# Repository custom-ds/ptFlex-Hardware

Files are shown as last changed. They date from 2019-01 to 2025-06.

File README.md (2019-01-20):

# Project: Traveler ptFlex
Following the sunsetting of the PTMini project, the ptFlex is the second generation of the ArduinoTrack APRS tracker.  

The ptFlex is based on the same ATMega processor and much of the same hardware as the ArduinoTrack, but a newer and smaller form factor.  The new form factor removes the larger Arduino Shield connectors that proved to be fragile and rarely used.  Instead, the digial pins have been replaced with a single "Qwiic" connector, conforming to Sparkfun's Qwiic standards.

[Sparkfun Qwiic Connector Standard](https://www.sparkfun.com/qwiic)

Board version 1.0.3 is release-candidate level, and is currently undergoing flight testing.

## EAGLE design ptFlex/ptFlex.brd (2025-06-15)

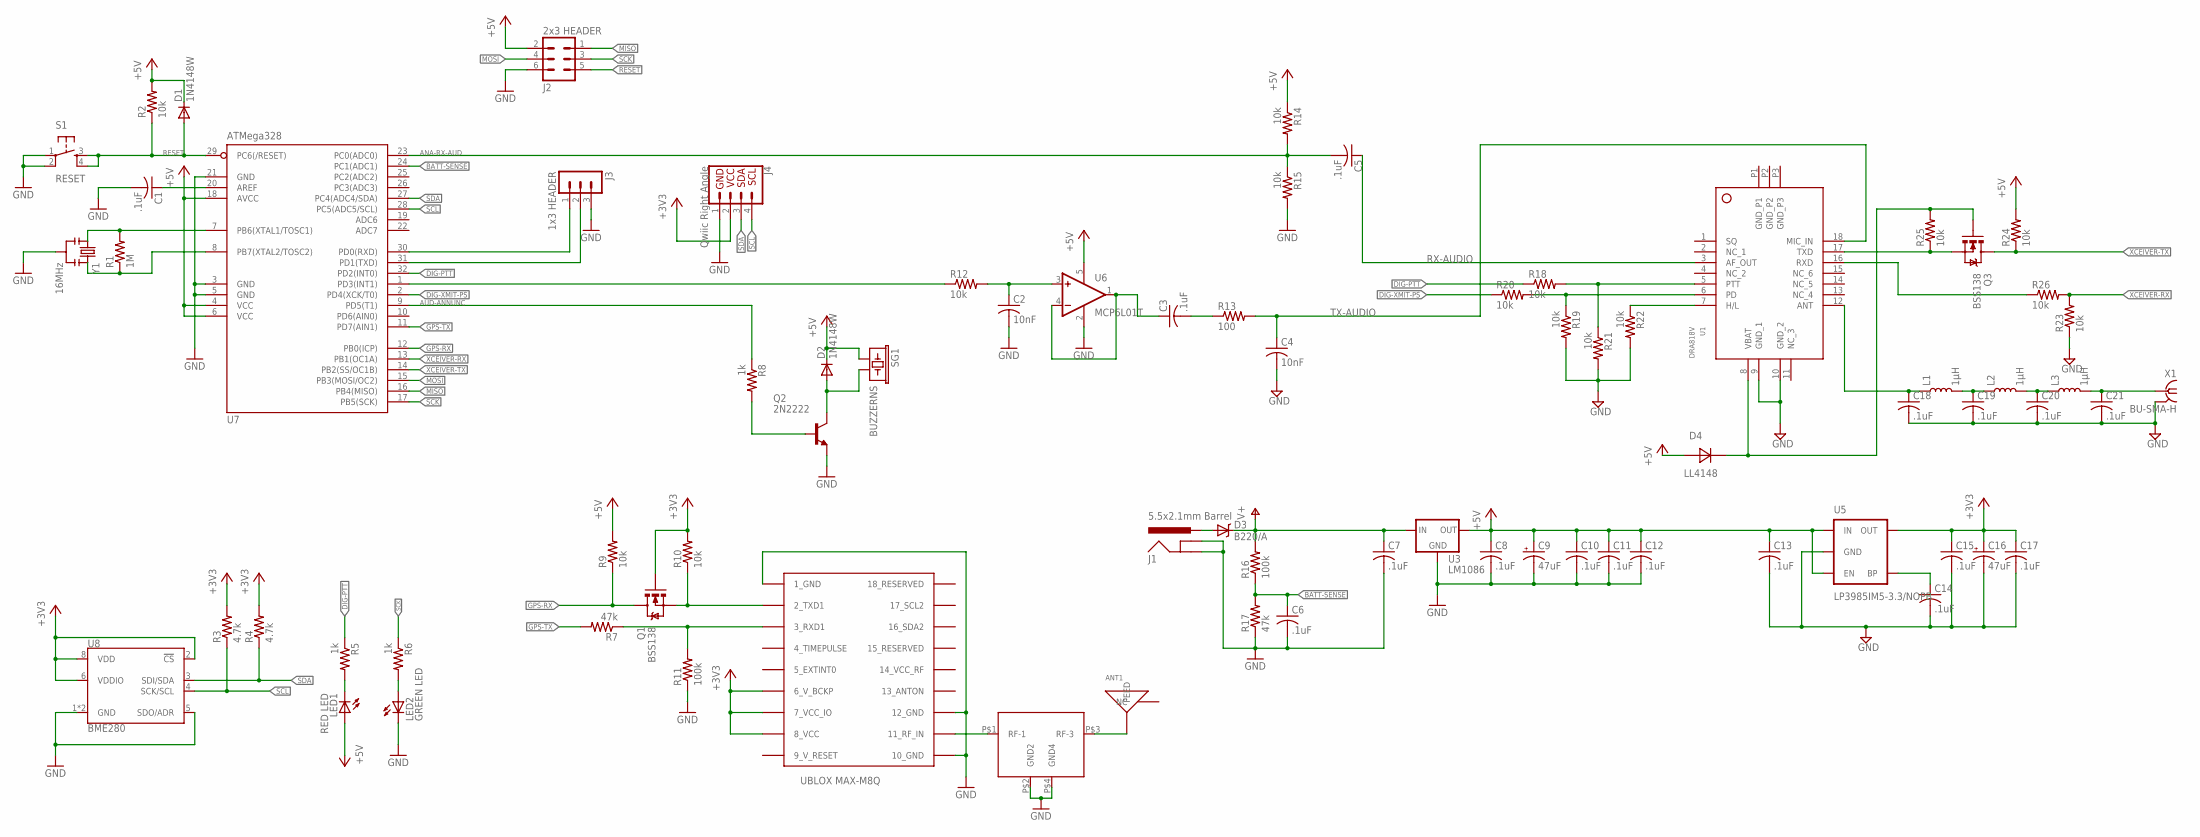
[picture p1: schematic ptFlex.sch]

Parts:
ANT1: GPS ANTENNA; 1575AT43A40; DIGIKEY 712-1003-1-ND
C1, C3, C5, C6, C7, C8, C10, C11, C12, C13, C14, C15, C17, C18, C19, C20, C21: .1uF; C0805; DIGIKEY 311-1361-1-ND
C2, C4: 10nF; C0805; DIGIKEY 399-1158-1-ND
C9, C16: 47uF; 153CLV-0605; DIGIKEY PCE3842CT-ND
D1, D2: 1N4148W; SOD123; DIGIKEY 1N4148W-FDICT-ND
D3: B220/A; SMA-DIODE; DIGIKEY 641-1258-1-ND
D4: LL4148; SOD-80
F1: MURATA-GPS-FILTER; DIGIKEY 583-1198-1-ND
J1: 5.5x2.1mm Barrel; POWER_JACK_SMD; DIGIKEY CP-002AHPJCT-ND
J2: 2x3 HEADER; MA03-2; DIGIKEY 952-2121-ND
J3: 1x3 HEADER; MA03-1; DIGIKEY 952-2264-ND
J4: Qwiic Right Angle; 1X04_1MM_RA; DIGIKEY 455-1804-1-ND
L1, L2, L3: 1µH; L0805
LED1: RED LED; CHIPLED_1206; DIGIKEY 160-1405-1-ND
LED2: GREEN LED; CHIPLED_1206; DIGIKEY 160-1169-1-ND
Q1, Q3: BSS138; SOT23; DIGIKEY BSS138KCT-ND
Q2: 2N2222; SOT23-BEC; DIGIKEY MMBT2222AFSCT-ND
R1: 1M; R0805; DIGIKEY 311-1.0MARCT-ND
R2, R9, R10, R12, R14, R15, R18, R19, R20, R21, R22, R23, R24, R25, R26: 10k; R0805; DIGIKEY 311-10.0KCRCT-ND
R3, R4: 4.7k; R0805; DIGIKEY 311-4.7KARCT-ND
R5, R6, R8: 1k; R0805; DIGIKEY 311-1.0KARCT-ND
R7, R17: 47k; R0805; DIGIKEY 311-47.0KCRCT-ND
R11, R16: 100k; R0805; DIGIKEY 311-100KCRCT-ND
R13: 100; R0805; DIGIKEY 311-100ARCT-ND
S1: RESET; TACTILE_SWITCH_SMD; DIGIKEY CKN9104CT-ND
SG1: BUZZERNS; BUZZER-12MM-NS; DIGIKEY 102-1155-ND
U1: DRA818V; SMD_DRA818
U2: UBLOX_MAX; DIGIKEY 672-1003-1-ND
U3: LM1086; TO263; DIGIKEY LM1086ISX-5.0/NOPBCT-ND
U5: LP3985IM5-3.3/NOPB; SOT23-5; DIGIKEY LP3985IM5-3.3/NOPBCT-ND
U6: MCP6L01T; SOT23-5; DIGIKEY MCP6L01T-E/OTCT-ND
U7: ATMega328; TQFP32-08; DIGIKEY ATMEGA328P-AU-ND
U8: BME280; LGA-8-2.5X2.5; DIGIKEY 828-1063-1-ND
X1: BU-SMA-H; DIGIKEY CONSMA001-ND
Y1: 16MHz; RESONATOR-SMD; DIGIKEY 478-5420-1-ND

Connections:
9_V_RESET: U2.9_V_RESET
+3V3: C15.1, C16.+, C17.1, J4.2, Q1.1 (G), R3.2, R4.2, R10.2, U2.6_V_BCKP, U2.7_VCC_IO, U2.8_VCC, U5.5 (OUT), U8.2 (!CS), U8.6 (VDDIO), U8.8 (VDD)
+5V: C8.1, C9.+, C10.1, C11.1, C12.1, C13.1, D1.C, D2.C, D4.ANODE, J2.2, LED1.A, R2.2, R9.2, R14.1, R24.2, SG1.+ (1), U3.2 (OUT), U5.1 (IN), U5.3 (EN), U6.5 (V+), U7.4 (VCC), U7.6 (VCC), U7.18 (AVCC)
ANA-RX-AUD: C5.2, R14.2, R15.1, U7.23 (PC0(ADC0))
AUD-ANNUNC: R8.1, U7.9 (PD5(T1))
BATT-SENSE: C6.1, R16.1, R17.2, U7.24 (PC1(ADC1))
DIG-PTT: R5.1, R18.1, U7.32 (PD2(INT0))
DIG-XMIT-PS: R20.1, U7.2 (PD4(XCK/T0))
GND: C1.2, C2.2, C4.2, C6.2, C7.2, C8.2, C9.-, C10.2, C11.2, C12.2, C13.2, C14.2, C15.2, C16.-, C17.2, C18.2, C19.2, C20.2, C21.2, F1.P$2 (GND2), F1.P$4 (GND4), J1.GND (GNDBREAK), J1.P$4 (GND), J2.6, J3.3, J4.1, LED2.C, Q2.E, R11.1, R15.2, R17.1, R19.2, R21.2, R22.2, R23.1, S1.1, S1.2, U1.9 (GND_1), U1.10 (GND_2), U2.1_GND, U2.10_GND, U2.12_GND, U3.1 (GND), U5.2 (GND), U6.2 (V-), U7.3 (GND), U7.5 (GND), U7.21 (GND), U8.1 (GND), U8.5 (SDO/ADR), U8.7 (GND), X1.2, X1.3 (2), X1.4 (2), X1.5 (2), Y1.2
GPS-RX: Q1.3 (D), R9.1, U7.12 (PB0(ICP))
GPS-TX: R7.2, U7.11 (PD7(AIN1))
MISO: J2.1, U7.16 (PB4(MISO))
MOSI: J2.4, U7.15 (PB3(MOSI/OC2))
unnamed: C2.1, R12.2, U6.3 (+IN)
unnamed: F1.P$1 (RF-1), U2.11_RF_IN
unnamed: ANT1.FEED, F1.P$3 (RF-3)
unnamed: C20.1, L2.2, L3.1
unnamed: C19.1, L1.2, L2.1
unnamed: C18.1, L1.1, U1.12 (ANT)
unnamed: C21.1, L3.2, X1.1
unnamed: D3.A, J1.VIN0 (PWR)
unnamed: D2.A, Q2.C, SG1.- (2)
unnamed: C4.1, R13.2, U1.18 (MIC_IN)
unnamed: C3.1, U6.1 (OUT), U6.4 (-IN)
unnamed: D4.CATHODE, Q3.1 (G), R25.2, U1.8 (VBAT)
unnamed: R12.1, U7.1 (PD3(INT1))
unnamed: R18.2, R21.1, U1.5 (PTT)
unnamed: Q1.2 (S), R10.1, U2.2_TXD1
unnamed: R19.1, R20.2, U1.6 (PD)
unnamed: R1.1, U7.8 (PB7(XTAL2/TOSC2)), Y1.3
unnamed: R7.1, R11.2, U2.3_RXD1
unnamed: R22.1, U1.7 (H/L)
unnamed: Q3.2 (S), R25.1, U1.17 (TXD)
unnamed: LED1.C, R5.2
unnamed: LED2.A, R6.2
unnamed: Q2.B, R8.2
unnamed: R26.1, U1.16 (RXD)
unnamed: C1.1, U7.20 (AREF)
unnamed: C14.1, U5.4 (BP)
unnamed: R1.2, U7.7 (PB6(XTAL1/TOSC1)), Y1.1
RESET: D1.A, J2.5, R2.1, S1.3, S1.4, U7.29 (PC6(/RESET))
RX-AUDIO: C5.1, U1.3 (AF_OUT)
RXD: J3.1, U7.30 (PD0(RXD))
SCK: J2.3, R6.1, U7.17 (PB5(SCK))
SCL: J4.4, R3.1, U7.28 (PC5(ADC5/SCL)), U8.4 (SCK/SCL)
SDA: J4.3, R4.1, U7.27 (PC4(ADC4/SDA)), U8.3 (SDI/SDA)
TX-AUDIO: C3.2, R13.1
TXD: J3.2, U7.31 (PD1(TXD))
V+: C7.1, D3.C, R16.2, U3.3 (IN)
XCEIVER-RX: R23.2, R26.2, U7.13 (PB1(OC1A))
XCEIVER-TX: Q3.3 (D), R24.1, U7.14 (PB2(SS/OC1B))

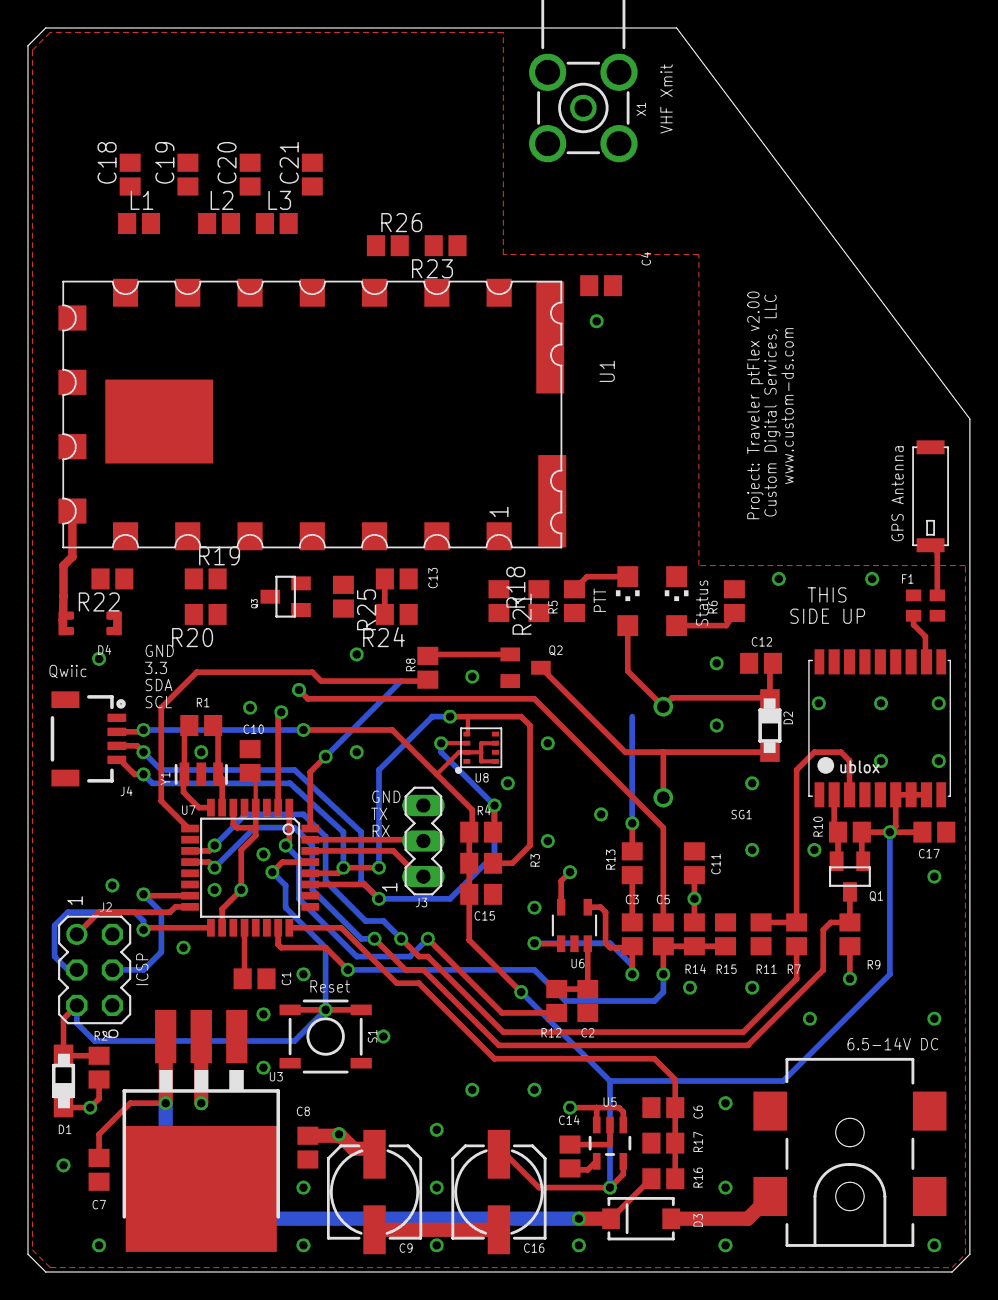
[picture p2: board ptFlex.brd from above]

Board: 4 copper layers, 67.3 x 88.9 mm, 76 parts (0 on the bottom side), 50 nets.

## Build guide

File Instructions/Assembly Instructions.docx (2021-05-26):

# Project: Traveler ptFlex v1.03

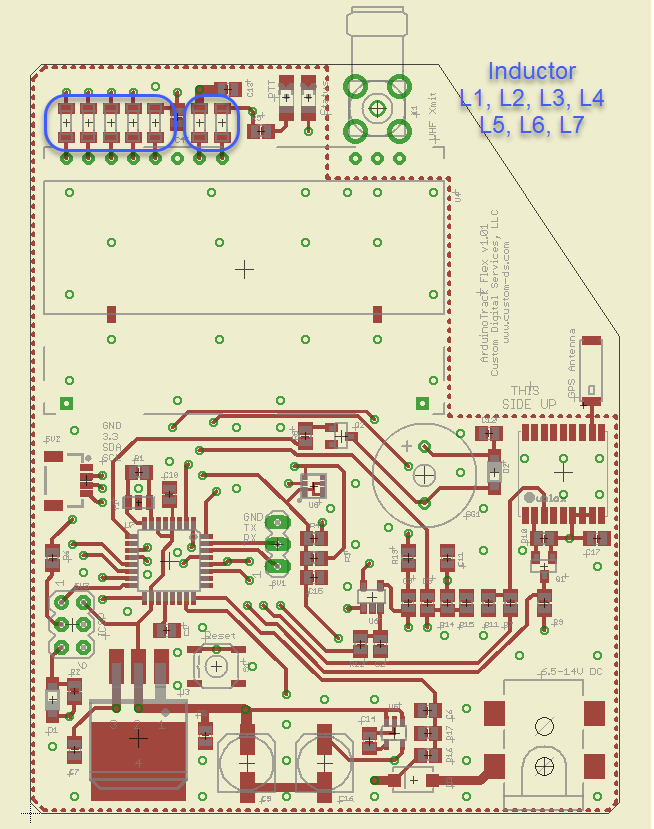
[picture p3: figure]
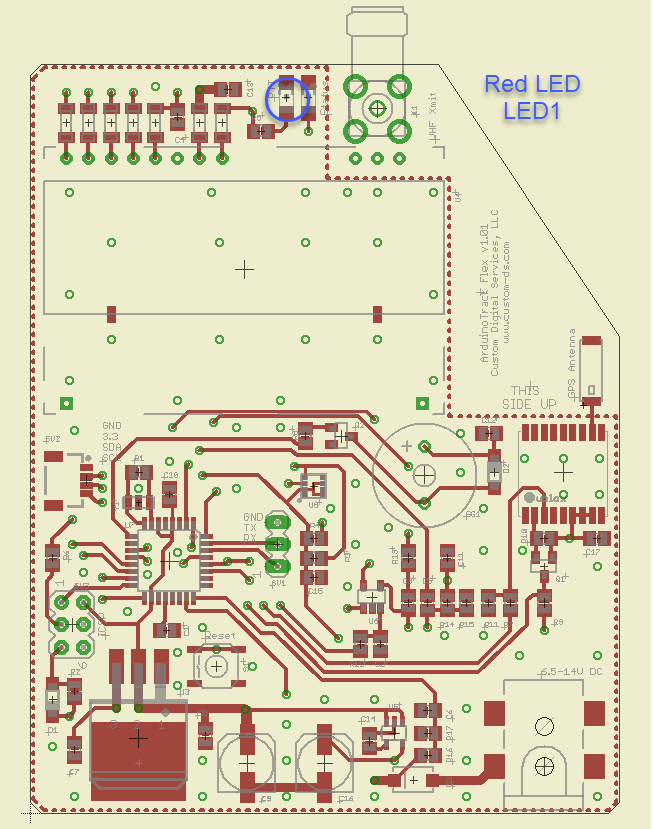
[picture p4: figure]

Inductors L1-L7 - 160Ω Notes: | Red LED LED1 Notes: Dark stripe to the top edge of PCB.

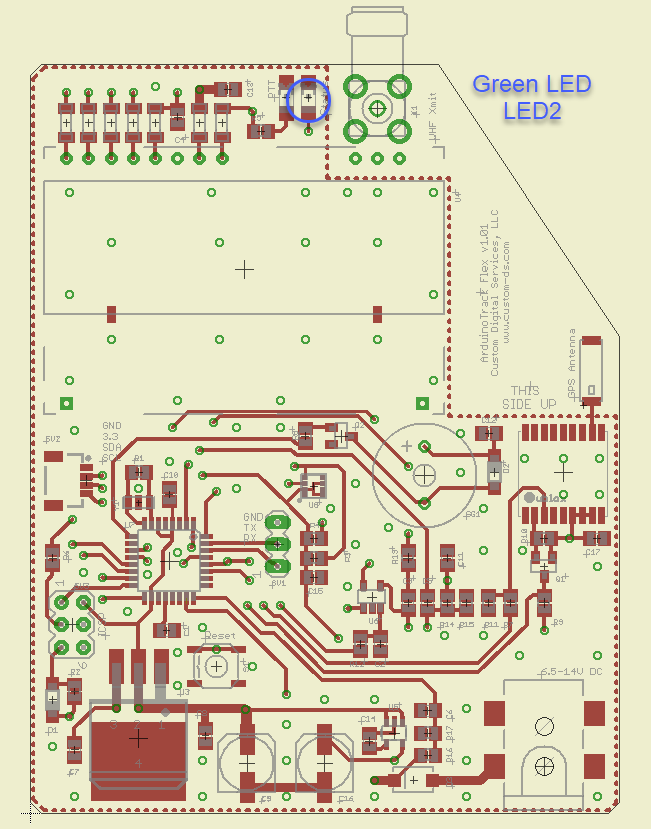
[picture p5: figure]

Green LED LED2 Notes: Dark stripe to the top edge of PCB. | MOSFET Q1 Notes:

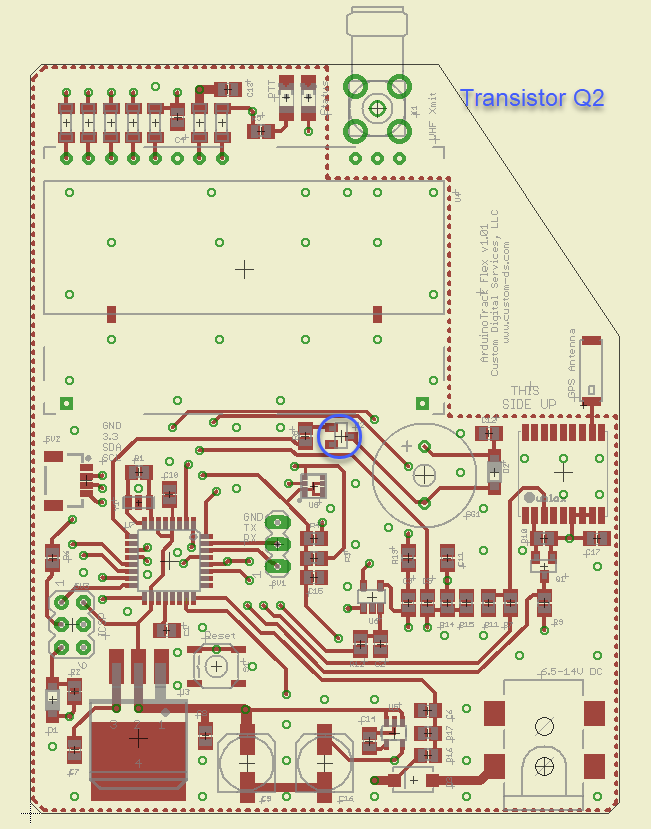
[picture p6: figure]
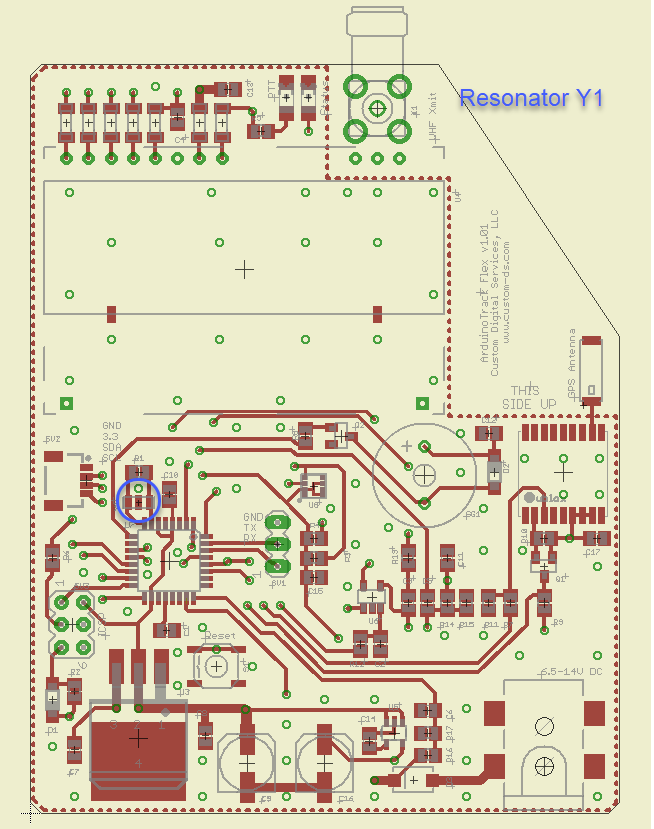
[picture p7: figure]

Transistor Q2 Notes: | Resonator Y1 Notes: 16MHz

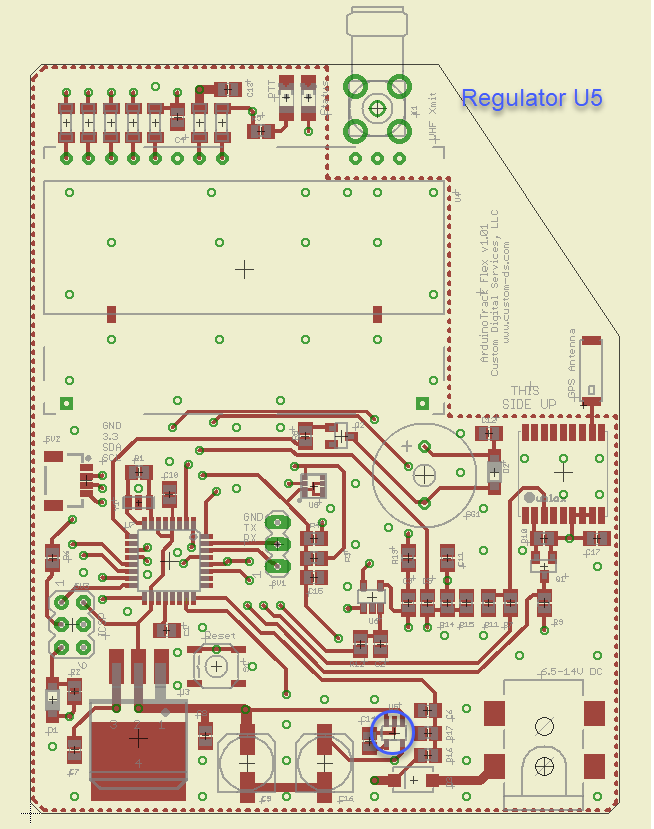
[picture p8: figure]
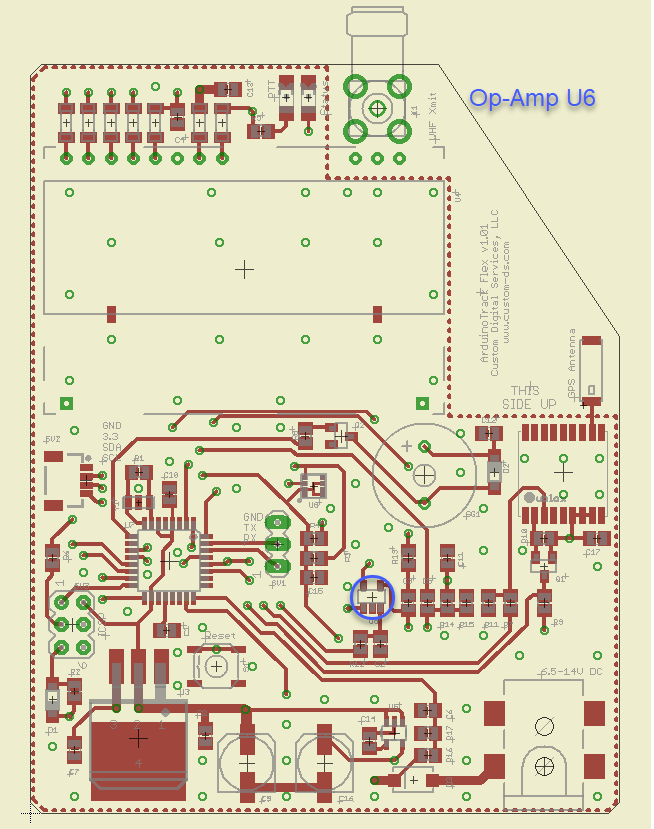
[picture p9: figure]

Regulator U5 Notes: | OpAmp U6 Notes:

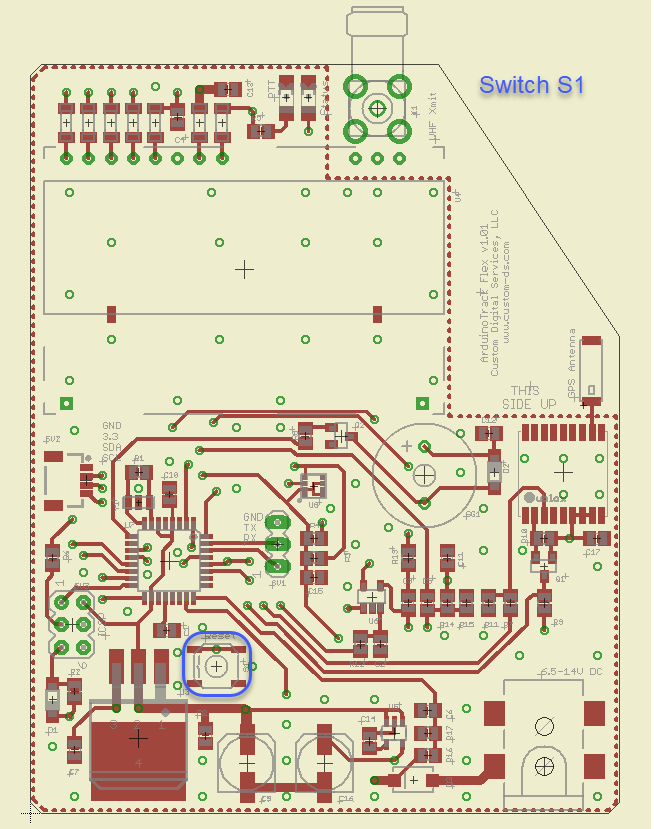
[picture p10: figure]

Switch S1 Notes: | Resistor R1 Notes: 1MΩ (Marking 105 or 1004)

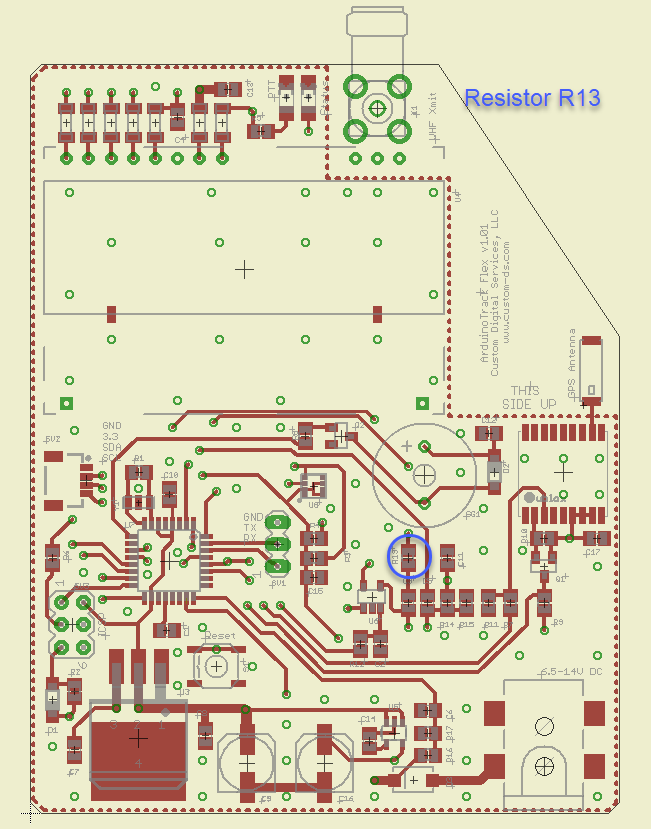
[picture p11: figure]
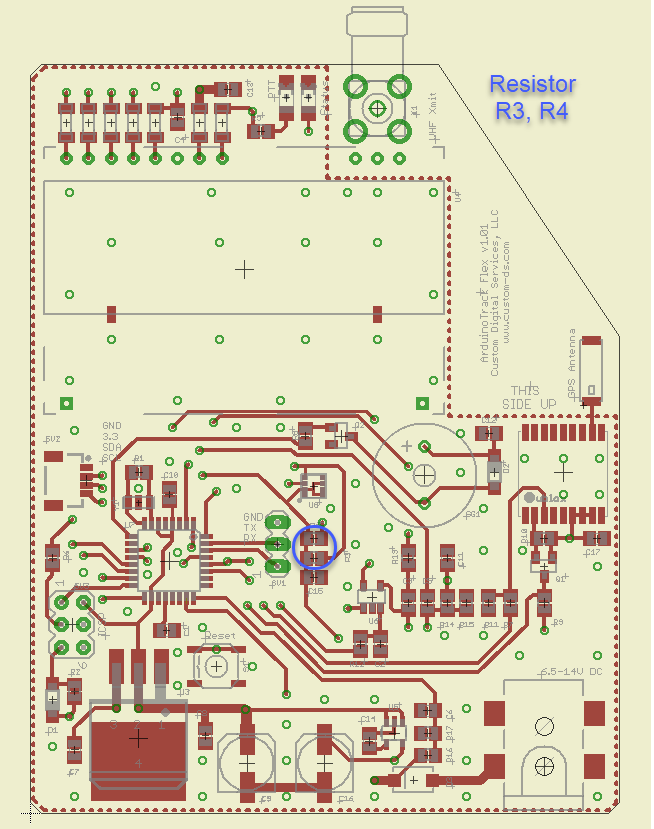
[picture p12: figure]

Resistor R13 Notes: 100Ω (Marking 101 or 1000) | Resistor R3-R4 Notes: 4.7kΩ (Marking 472 or 4701)

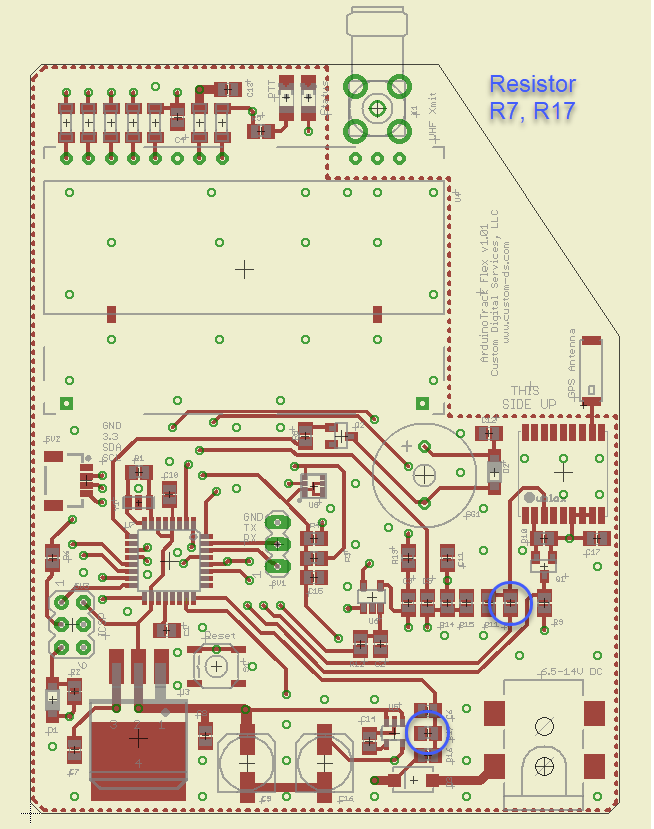
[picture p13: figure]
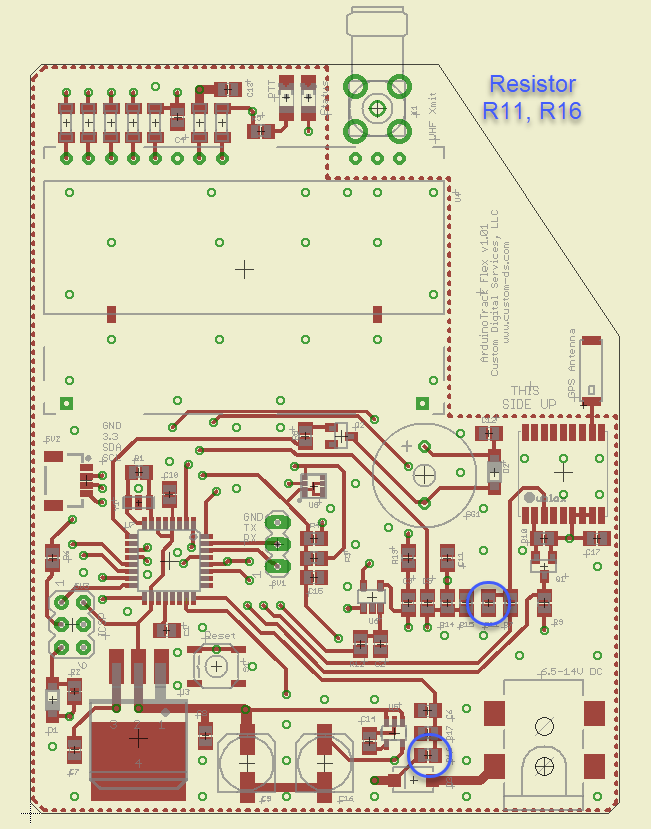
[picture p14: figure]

Resistor R7, R17 Notes: 47kΩ (Marking 473 or 4702) | Resistor R11, R16 Notes: 100kΩ (Marking 104 or 1003)

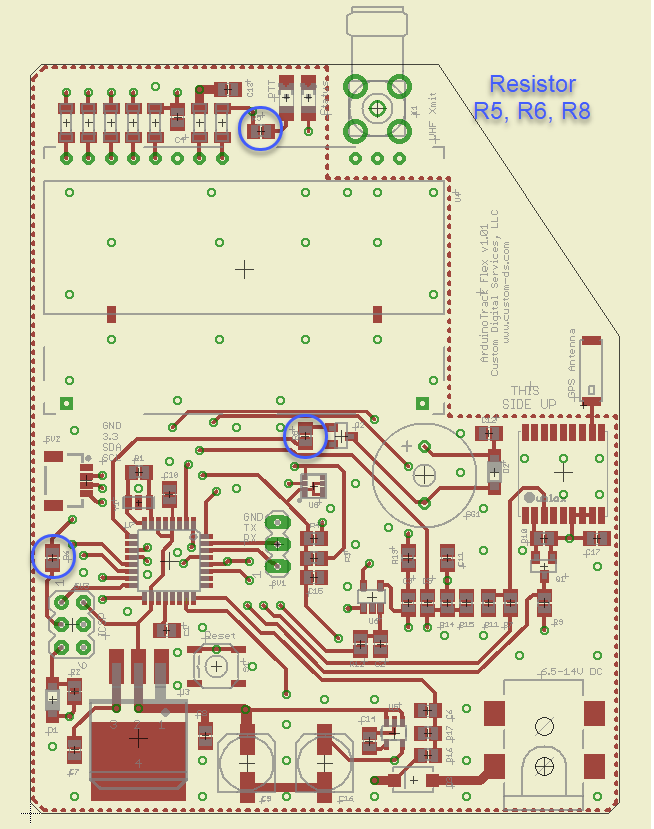
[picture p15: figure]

Resistor R5, R6, R8 Notes: 1kΩ (Marking 102 or 1001) | Resistor R2, R9, R10, R12, R14, R15 Notes: 10kΩ (Marking 103 or 1002)

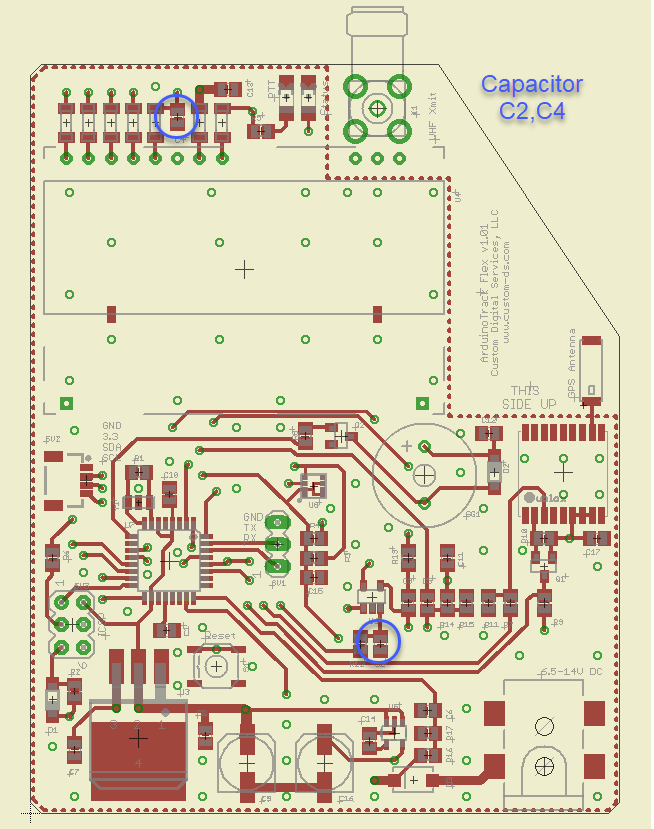
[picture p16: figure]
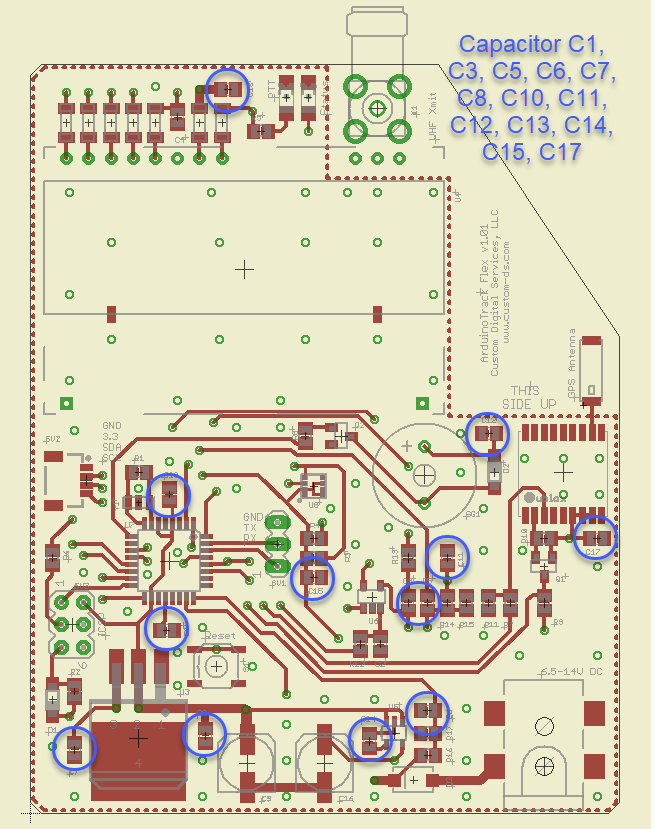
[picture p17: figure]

Capacitor C2, C4 Notes: 10nF | Capacitor C1, C3, C5-C8, C10-C15, C17 Notes: .1µF

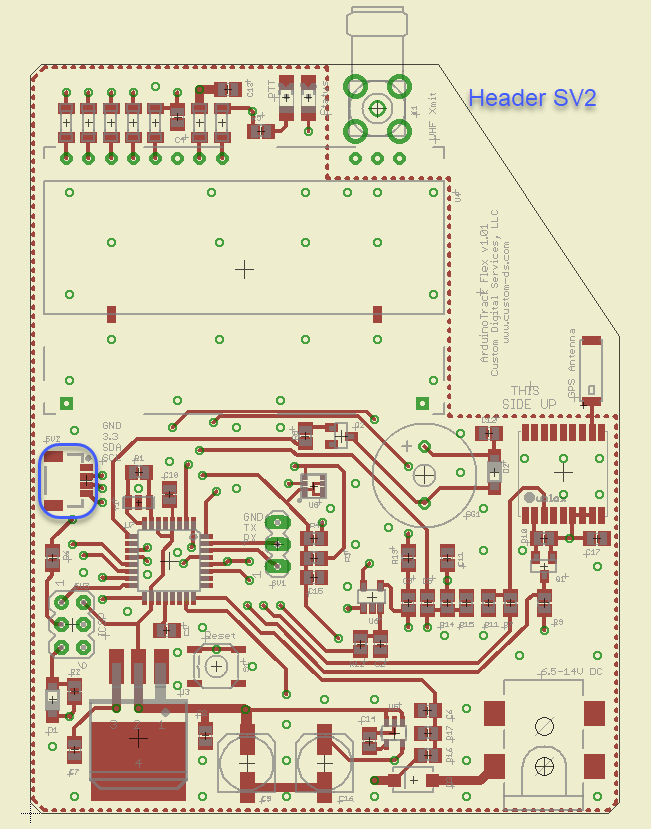
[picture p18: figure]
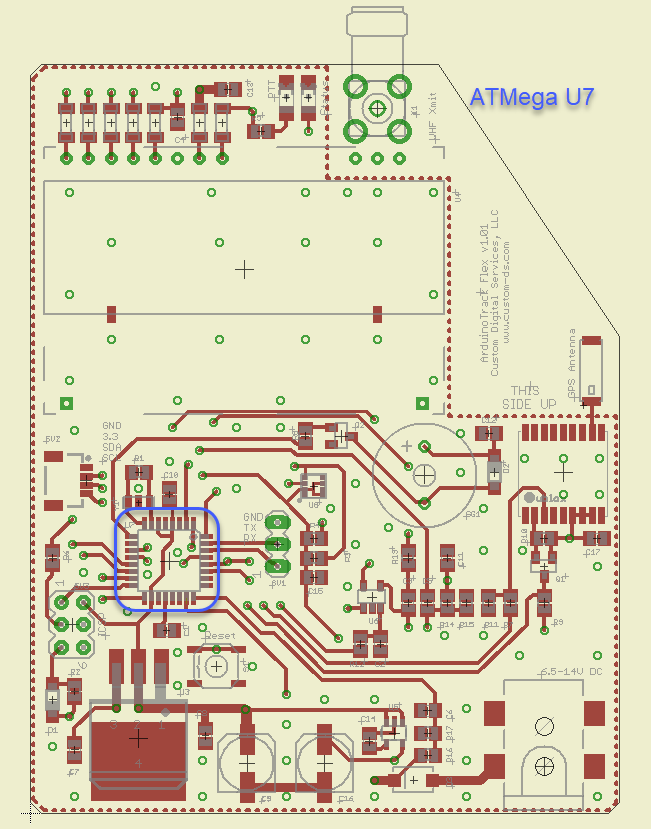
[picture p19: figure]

Header SV2 Notes: | ATMega U7 Notes: Dot to upper-right corner.

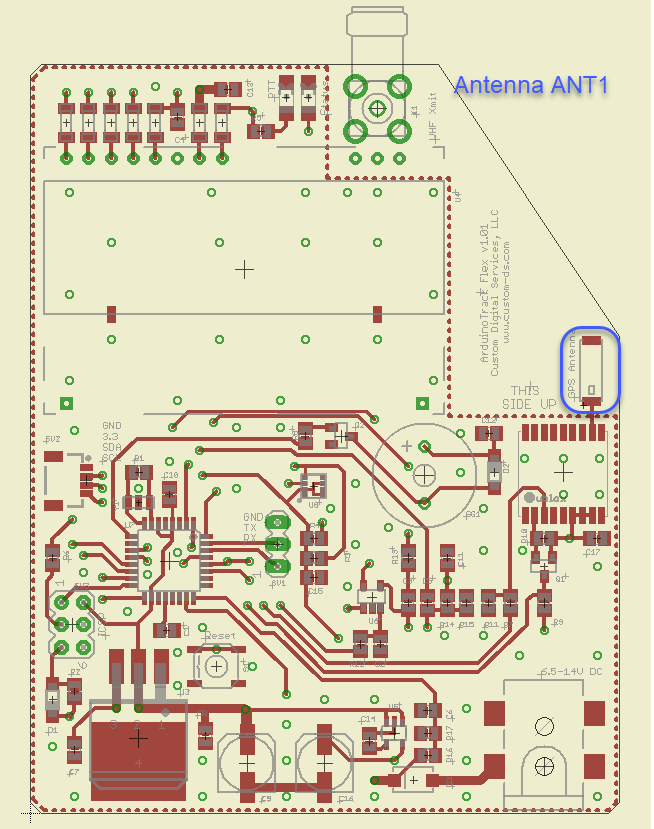
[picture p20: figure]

GPS Antenna Filter Notes: | Antenna ANT1 Notes: Dot to bottom.

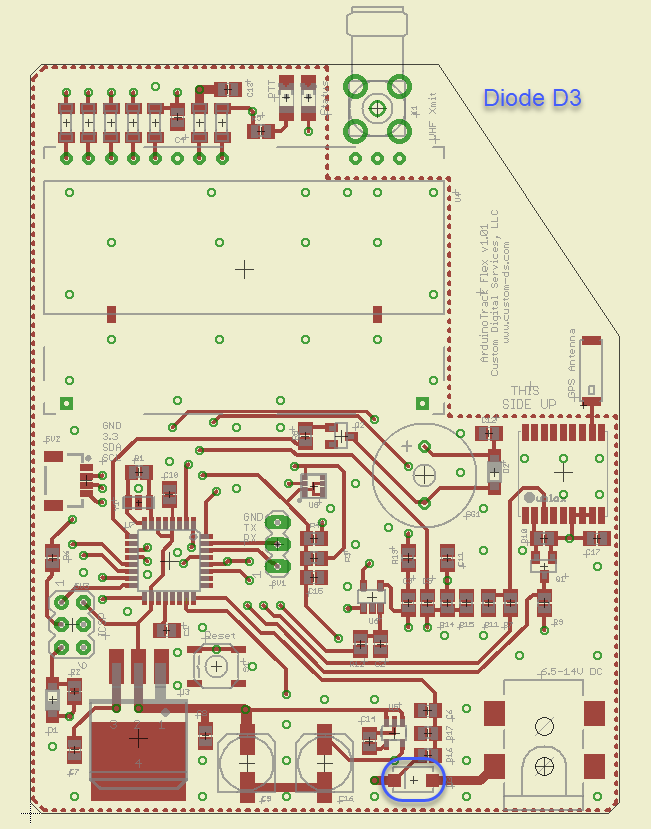
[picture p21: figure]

Diodes D1-D2 Notes: D1 is stripe down, D2 is stripe up. | Diode D3 Notes: Diode stripe to left.

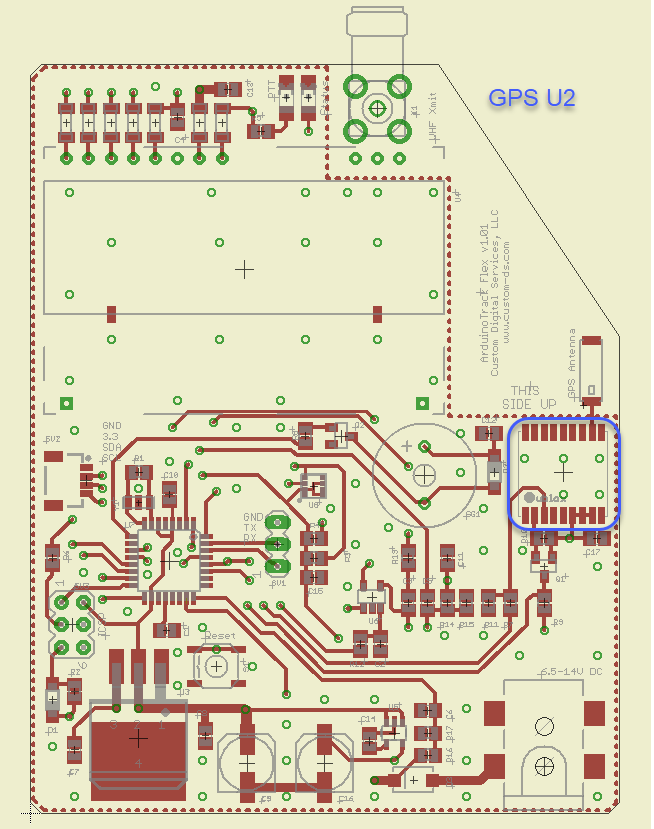
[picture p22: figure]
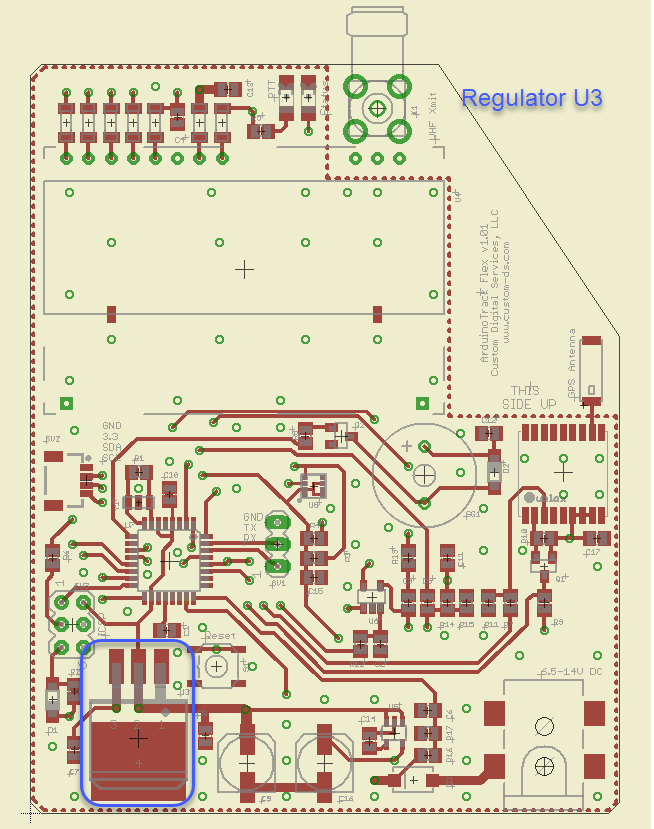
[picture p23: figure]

GPS U2 Notes: Red dot to bottom-left. | Regulator U3 Notes:

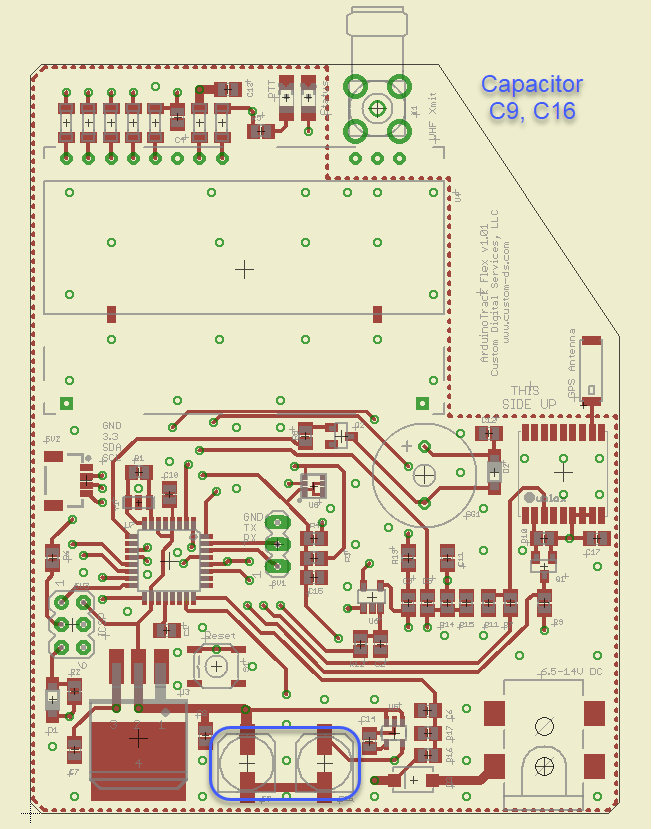
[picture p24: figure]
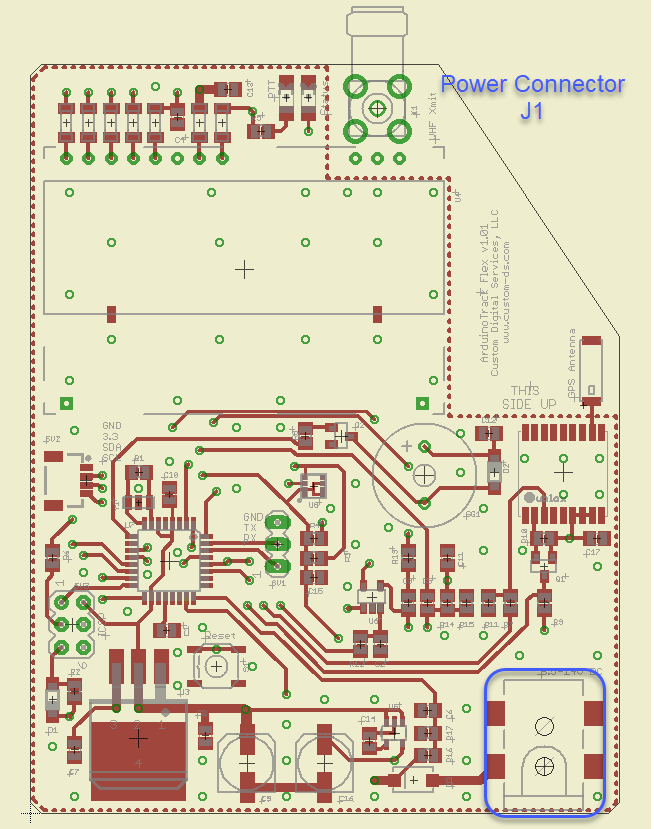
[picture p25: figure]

Capacitor C9, C16 Notes: 47µF Black stripe to bottom. | Connector J1 Notes:

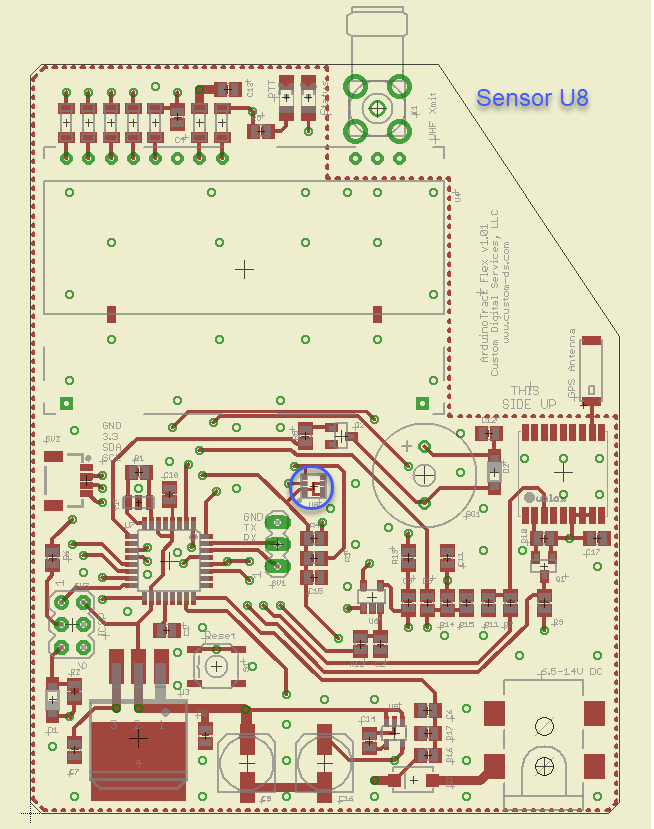
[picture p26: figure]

Sensor U8 Notes: Vent hole to top. May be easier to place by hand after reflow.

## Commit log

2018-02-23 Initial commit of the second generation tracker
    [Flex.brd, Flex.sch]
2018-12-25 Check In for Flex 1.0.1
    Final fab-ready board for 1.0.1.
    [BOM.csv, BOM.xlsx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]
2018-12-26 Fixed alignment for transmitter board
    Shifted piezo down, and SMA up to make room for transmitter board.
    [Flex.brd, Flex.sch]
2018-12-26 Version 1.0.2 Final commit
    Generated Gerber files and sent to production house.
    [Flex.gbr]
2019-01-20 Rebranding to ptFlex
    Changed name, moved piezo slightly down on board to increase clearance. Updated to 1.03.
    Reorganized assembly instructions to provide assembly details.
    [BOM.csv, BOM.xlsx, ptFlex.brd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]
2019-01-20 More rebranding changes.
    [BOM.csv, BOM.xlsx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]
2019-01-23 Added digikey part numbers to missing parts.
    [BOM.xlsx, ptFlex.brd, ptFlex.sch]
2019-04-14 Added GPS filter
    Version 1.04
    [ptFlex.brd, ptFlex.sch]
2019-05-26 Gerbers for 1.0.4
    [ptFlex.gbr]
2019-07-13 Minor tweak to piezo to open up ground plane
    [ptFlex.brd]
2021-05-26 Final for version 1.02
    Switching to version 2.0 which does away with backwards compatibility for the RadioMetrix modules.
2025-06-15 Final check in for hardware version 1
    [ptFlex.brd, ptFlex.sch]

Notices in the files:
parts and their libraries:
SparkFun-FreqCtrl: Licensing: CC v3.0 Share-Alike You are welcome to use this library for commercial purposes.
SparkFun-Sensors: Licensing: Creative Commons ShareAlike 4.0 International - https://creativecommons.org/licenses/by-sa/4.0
